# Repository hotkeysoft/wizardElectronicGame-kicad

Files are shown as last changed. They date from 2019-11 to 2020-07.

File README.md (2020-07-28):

# Wizard Electronic Game
Rev A October 2019

### Handheld Electronic Game
- ATmega328P microcontroller running at 12MHz
- 10 push buttons with red LEDs
- 4 buttons for game mode
- Buzzer
- Tag-Connect for programming
- Runs on 3 AAA batteries

The microcontroller runs a [TMS1000-series emulator](https://github.com/hotkeysoft/emulators) I made.

Two ROMs are loaded on the emulator: **Merlin (TMS1100)** and **Master Merlin (TMS1400)** (by *Parker Brothers*).

By default the game boots in Merlin mode. To play Master Merlin, press any of the four mode buttons while turning on the console.

Images
============
|Front | Back |
|---|---|
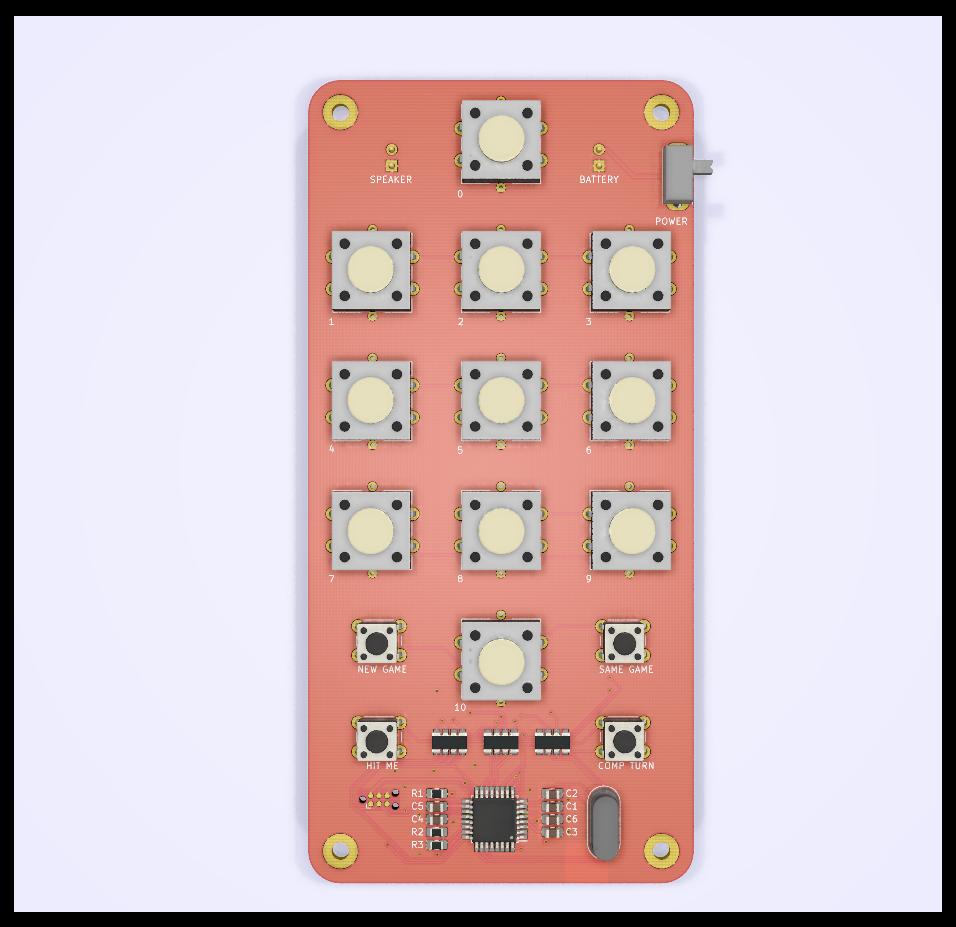
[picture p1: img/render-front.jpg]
Render Front
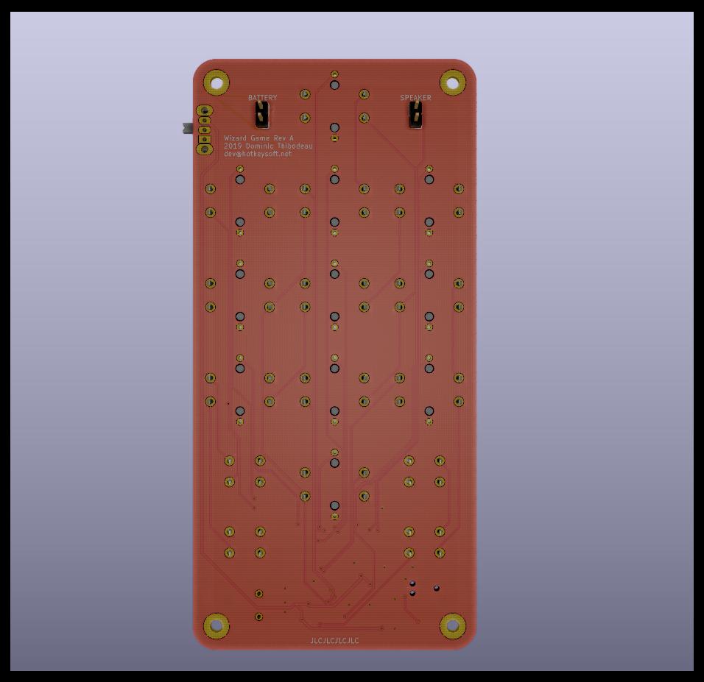
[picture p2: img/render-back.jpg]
Render Back
|||

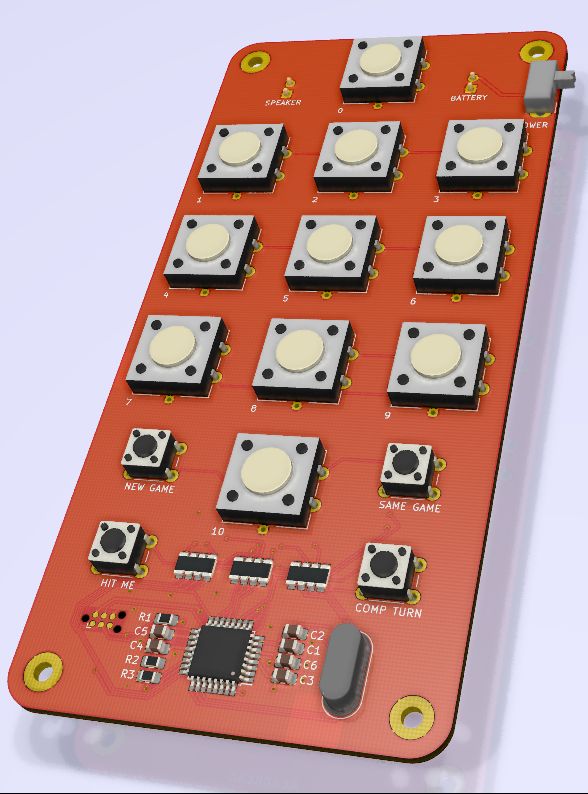
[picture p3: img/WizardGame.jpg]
Render


### Schematics (pdf)
- [Complete schematics](./img/schema.pdf)

### PCB Images (svg)
- [Top](./img/pcb-front.svg)
- [Bottom](./img/pcb-back.svg)

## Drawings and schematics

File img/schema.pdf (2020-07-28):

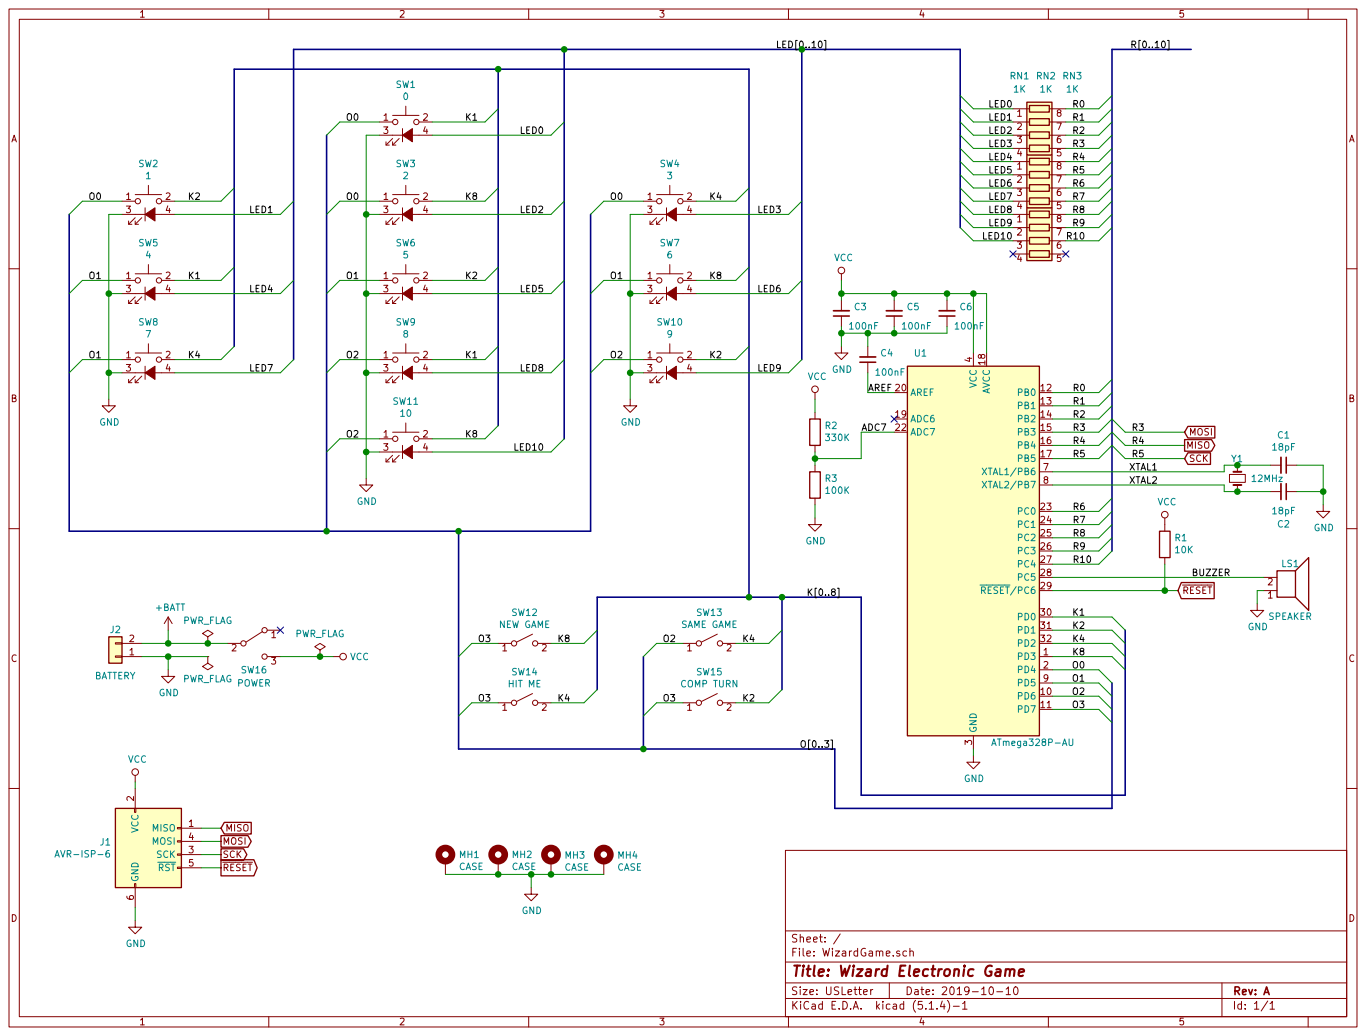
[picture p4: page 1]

2 SCK 3 MOSI 4 RST 5 GND

Id: 1/1 Title: Wizard Electronic Game

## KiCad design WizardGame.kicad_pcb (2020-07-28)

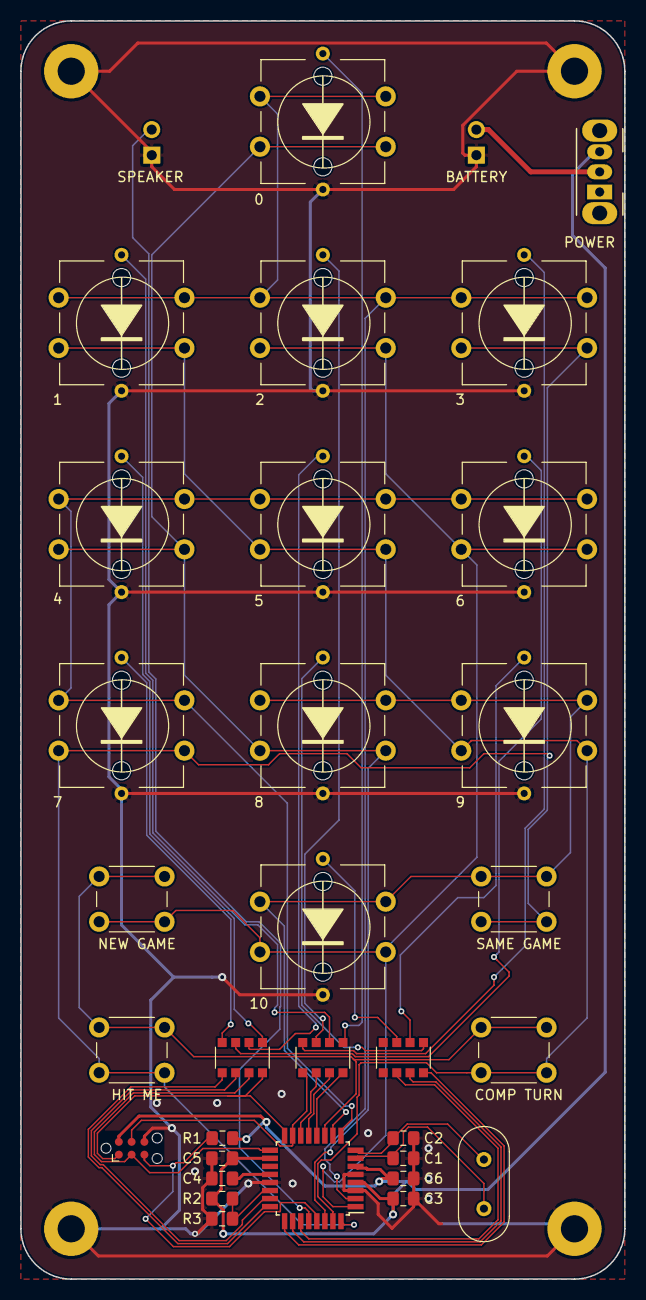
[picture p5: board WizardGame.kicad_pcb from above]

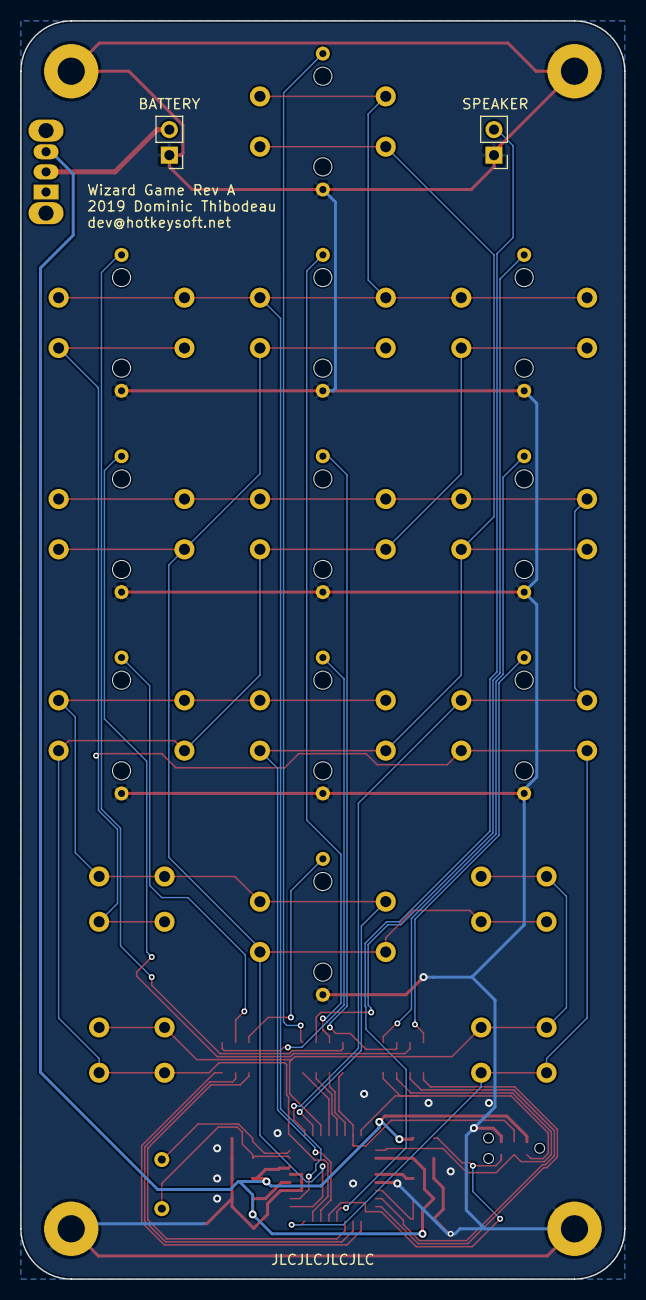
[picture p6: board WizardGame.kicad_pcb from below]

Board: 2 copper layers, 60.0 x 125.0 mm, 37 parts (2 on the bottom side), 39 nets.

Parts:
C1, C2: 18pF; C_0805_2012Metric_Pad1.15x1.40mm_HandSolder
C3, C4, C5, C6: 100nF; C_0805_2012Metric_Pad1.15x1.40mm_HandSolder
J1: AVR-ISP-6; Tag-Connect_TC2030-IDC-NL_2x03_P1.27mm_Vertical
J2: BATTERY; PinHeader_1x02_P2.54mm_Vertical
LS1: SPEAKER; PinHeader_1x02_P2.54mm_Vertical
MH1, MH2, MH3, MH4: CASE; MountingHole_2.7mm_Pad
R1: 10K; R_0805_2012Metric_Pad1.15x1.40mm_HandSolder
R2: 330K; R_0805_2012Metric_Pad1.15x1.40mm_HandSolder
R3: 100K; R_0805_2012Metric_Pad1.15x1.40mm_HandSolder
RN1, RN2, RN3: 1K; R_Array_Convex_4x1206
SW1: 0; SW_PUSH-12mm_LED
SW2: 1; SW_PUSH-12mm_LED
SW3: 2; SW_PUSH-12mm_LED
SW4: 3; SW_PUSH-12mm_LED
SW5: 4; SW_PUSH-12mm_LED
SW6: 5; SW_PUSH-12mm_LED
SW7: 6; SW_PUSH-12mm_LED
SW8: 7; SW_PUSH-12mm_LED
SW9: 8; SW_PUSH-12mm_LED
SW10: 9; SW_PUSH-12mm_LED
SW11: 10; SW_PUSH-12mm_LED
SW12: NEW GAME; SW_PUSH_6mm
SW13: SAME GAME; SW_PUSH_6mm
SW14: HIT ME; SW_PUSH_6mm
SW15: COMP TURN; SW_PUSH_6mm
SW16: POWER; SW_CuK_OS102011MA1QN1_SPDT_Angled
U1: ATmega328P-AU; TQFP-32_7x7mm_P0.8mm
Y1: 12MHz; Crystal_HC49-4H_Vertical

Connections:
+BATT: J2.2, SW16.2
/ADC7: R2.1, R3.2, U1.22
/AREF: C4.1, U1.20
/BUZZER: LS1.2, U1.28
/K1: SW1.2, SW5.2, SW9.2, U1.30
/K2: SW2.2, SW6.2, SW10.2, SW15.2, U1.31
/K4: SW4.2, SW8.2, SW13.2, SW14.2, U1.32
/K8: SW3.2, SW7.2, SW11.2, SW12.2, U1.1
/LED0: RN1.1, SW1.4
/LED1: RN1.2, SW2.4
/LED2: RN1.3, SW3.4
/LED3: RN1.4, SW4.4
/LED4: RN2.1, SW5.4
/LED5: RN2.2, SW6.4
/LED6: RN2.3, SW7.4
/LED7: RN2.4, SW8.4
/LED8: RN3.1, SW9.4
/LED9: RN3.2, SW10.4
/LED10: RN3.3, SW11.4
/O0: SW1.1, SW2.1, SW3.1, SW4.1, U1.2
/O1: SW5.1, SW6.1, SW7.1, SW8.1, U1.9
/O2: SW9.1, SW10.1, SW11.1, SW13.1, U1.10
/O3: SW12.1, SW14.1, SW15.1, U1.11
/R0: RN1.8, U1.12
/R1: RN1.7, U1.13
/R2: RN1.6, U1.14
/R6: RN2.6, U1.23
/R7: RN2.5, U1.24
/R8: RN3.8, U1.25
/R9: RN3.7, U1.26
/R10: RN3.6, U1.27
/XTAL1: C1.2, U1.7, Y1.1
/XTAL2: C2.2, U1.8, Y1.2
GND: C1.1, C2.1, C3.1, C4.2, C5.1, C6.1, J1.6, J2.1, LS1.1, MH1.1, MH2.1, MH3.1, MH4.1, R3.1, SW1.3, SW2.3, SW3.3, SW4.3, SW5.3, SW6.3, SW7.3, SW8.3, SW9.3, SW10.3, SW11.3, U1.3, U1.5, U1.21
MISO: J1.1, RN2.8, U1.16
MOSI: J1.4, RN1.5, U1.15
SCK: J1.3, RN2.7, U1.17
VCC: C3.2, C5.2, C6.2, J1.2, R1.2, R2.2, SW16.3, U1.4, U1.6, U1.18
~RESET: J1.5, R1.1, U1.29

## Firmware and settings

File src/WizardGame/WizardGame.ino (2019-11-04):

#include "rom.h"
#include "TMS1000.h"

// PD0..PD3
#define K1 0
#define K2 1
#define K4 2
#define K8 3

// PD4..PD7
#define O0 4
#define O1 5
#define O2 6
#define O3 7

// PC5
#define O4 19

// PB0..PB5, PC0..PC4
#define R0 8
#define R1 9
#define R2 10
#define R3 11
#define R4 12
#define R5 13
#define R6 14
#define R7 15
#define R8 16
#define R9 17
#define R10 18

bool masterMerlin = false;
const int stepDelayMerlin = 10;
const int stepDelayMasterMerlin = 7;

int stepDelay;

// Buttons connected to K1-K8
// Invert logic because we use pullups instead of pulldowns
void inputKCallback() {
  TMS1000::g_cpu.K = (PIND & 15) ^ 15;
}

// LED connected to R0-R10
void outputRCallback(TMS1000::BYTE pin, bool state) {
  digitalWrite(R0+pin, state);
}

void outputOCallback(TMS1000::BYTE val) {
  digitalWrite(O4, val & 1);
  uint8_t newVal = 0xFF;
  if (!(val & 1)) {
    switch(val & 15) {
      case 0: newVal =   0b11101111; break;
      case 4: newVal =   0b11011111; break;
      case 8: newVal =   0b10111111; break;
      case 12: newVal = 0b01111111; break; 
    }
  }
  PORTD = newVal;    
}

bool checkAnyButton() {
  PORTD = 0b00001111; 
  bool button =  ((PIND & 15) != 15);
  PORTD = 0b11111111;
  return button;  
}

bool checkNoButton() {
  PORTD = 0b00001111;
  delay(10);
  bool button =  ((PIND & 15) == 15);
  PORTD = 0b11111111;
  return button;    
}

void setup() {
  
  pinMode(K1, INPUT_PULLUP);
  pinMode(K2, INPUT_PULLUP);
  pinMode(K4, INPUT_PULLUP);
  pinMode(K8, INPUT_PULLUP);  

  pinMode(R0, OUTPUT);
  pinMode(R1, OUTPUT);
  pinMode(R2, OUTPUT);
  pinMode(R3, OUTPUT);
  pinMode(R4, OUTPUT);
  pinMode(R5, OUTPUT);
  pinMode(R6, OUTPUT);
  pinMode(R7, OUTPUT);
  pinMode(R8, OUTPUT);
  pinMode(R9, OUTPUT);
  pinMode(R10, OUTPUT);

  pinMode(O0, OUTPUT);
  pinMode(O1, OUTPUT);
  pinMode(O2, OUTPUT);
  pinMode(O3, OUTPUT);
  pinMode(O4, OUTPUT);
 
  TMS1000::SetInputKCallback(inputKCallback);
  TMS1000::SetOutputOCallback(outputOCallback);
  TMS1000::SetOutputRCallback(outputRCallback);

  // By default we load Merlin, if any pey is pressed at power up, load Master Merlin  
  if (checkAnyButton()) {
    do {
      outputRCallback(0, true);
      outputRCallback(10, true);
      delay(200);
      outputRCallback(0, false);
      outputRCallback(10, false);
      delay(200);
    }
    while (!checkNoButton());

    outputRCallback(0, false);
    outputRCallback(10, false);
    masterMerlin = true;
  }  
  
  if (!masterMerlin) {
    // Merlin Game    
    TMS1000::Init(TMS1000::CPU_TMS1100, 2048, 128); 
    TMS1000::g_memory.ROM = merlinRom;  
    stepDelay = stepDelayMerlin;
  } else {
    // Master Merlin Game
    TMS1000::Init(TMS1000::CPU_TMS1400, 4096, 128); 
    TMS1000::g_memory.ROM = masterMerlinRom;
    stepDelay = stepDelayMasterMerlin;
  }
  TMS1000::Reset();  
}

void loop() {
  TMS1000::Step();
  delayMicroseconds(stepDelay);
}

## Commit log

2019-10-13 Merlin + Simon Games
    [MerlinGame.kicad_pcb, MerlinGame.sch]
2019-10-22 Updated silkscreen, added plots
    [MerlinGame-B_Cu.gbr, MerlinGame-B_Mask.gbr, MerlinGame-B_SilkS.gbr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]
2019-10-23 Removed battery holes
    [MerlinGame-B_Cu.gbr, MerlinGame-B_Mask.gbr, MerlinGame-B_SilkS.gbr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]
2019-11-04 Added dimensions. Changed resistor value for LEDs. Fixed mode switch code
    [MerlinGame.kicad_pcb, MerlinGame.sch]
2020-07-28 Renamed, cleanup
    [WizardGame-B_Cu.gbr, WizardGame-B_Mask.gbr, WizardGame-B_SilkS.gbr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]
2020-07-28 Added submodule, updated paths
    [WizardGame.kicad_pcb]
